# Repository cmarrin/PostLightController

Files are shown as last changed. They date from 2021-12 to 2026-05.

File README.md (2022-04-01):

# PostLightController

## Introduction
This is a controller for post lights along my fence. Each post has a NeoPixels 8 pixel ring and an Arduino Nano to drive it.
It receives serial data from a Raspberry Pi with 0-5v levels and no line conditioning other than 0.01uf capacitors on the input
and output serial lines. Data comes in on pin 11 and is sent out on pin 10. Post Light Controllers are connected in serial. The
previous controller sends data to the next. Each serial packet contains an address. An address of 0 sends the packet to all
controller, so every byte is simply passed on. If the address is 1, this packet is for the receiving controller. It consumes it
and doesn't send it on. If it is greater than 1 the address is decremented and the packet is sent to the next controller. So for
instance an address of 5 is consumed by the 5th controller in the chain.

SoftSerial is used to receive and send packets. Each packet consists of a variable number of bytes, starting with a lead-in ('('),
address, command and size. This is followed by <size> bytes of payload then by a checksum byte and a lead-out (')'). The command
tells the controller what sequence to run. For instance it can set a constant color ('c') of flicker the lights to looks like a
burning candle ('f'). The payload is specific to the command. But most commands start with a color as a byte each of hue,
saturation and value (brightness). 
	
## Interpreter
	
In order to avoid having to reprogram each post light controller whenever a command is added or changed, the system has an interpreter
for a custom language, Clover. See https://github.com/cmarrin/Clover. Clover uses the concepts of commands for calling functions to perform the various lighting effects. Because of the serial interface, commands for the post lights are a single character. You write a function for init and loop (in Arduino terms), indicate how many params are to be passed and associate it with a single character command string. The params passed to the serial interface must match the number of params specified in the command. The Interpreter init() function is called, passing the command and params. Those params are also available to the loop() function. The loop() function returns an int which is the number of milliseconds to delay before calling loop again. This allows accurate timing for the lighting effects.
	
Clover has a mechanism for adding modules, custom native functions for specific functionality. The post lights use a circular NeoPixel array with 8 addressable RGB LEDs (https://www.ebay.com/itm/392044823820). So the PostLightController adds a NativeColor module. This adds the concept of 4 color "registers" which can be manipulated by the functions in the module. There are functions to load a color (3 byte HSV) from the Params into one of the registers, loading and storing one color component (HSV) in one of the registers, and setting one light or all lights from a color register.

## Uploading
	
Commands are uploaded to the Aduino from the serial port in 64 byte binary chunks. The chunks are actually 66 bytes: 64 data bytes preceeded by a 2 byte offset of where to put the bytes in EEPROM. The Clover source is compiled on Mac into a series of 64 byte chunks saved to disk. A Node Red project (https://github.com/cmarrin/PondController-node-red-mac and https://github.com/cmarrin/PondController-node-red-mac) is used to upload. The Mac version is for testing but the system is intended to be run on a Raspberry Pi connected through its hardware serial port. You can connect to a PostLightController board from a USB to Serial board connected to the Mac and use the Node Red project to upload using the Send Executable button. See below for how to set up Node Red on Mac and RPi. The Mac compiler is a command line tool. You give it the Clover source file with the '-s' option to output a sequence of files with the same name as the input file minus the '.clvr' suffix, with a 2 digit sequence number and '.arlx'. These file are each 66 bytes long except for the last one, which is as long as needed.
	
## Installing Node-Red on Mac

To install the Node-Red PostLightController project on Mac, follow these steps:

1. Install Node.js (https://phoenixnap.com/kb/install-npm-mac).
2. Use the npm package manager to install Node-Red (https://nodered.org/docs/getting-started/local).
3. Clone the Mac Node-Red project (https://github.com/cmarrin/PondController-node-red-mac) into ~/.node-red/projects/PondController-node-red-mac/
4. In a Terminal shell run 'node-red'
	
The Node-Red Serial Out node is set to /dev/tty.usbserial-AD02CUJ5 for use with my USB to Serial board, which is similar to this one: https://www.ebay.com/itm/223507758747. Yours may be different. You can 'ls /dev/tty.usbserial-*' to see the name on your machine. If you have more than one board connected disconnect the others so you can positively identify the board you're using. Note that if you're connected directly connected to your Arduino to program it, that serial port will show up. Unplug it temporarily so you can find the one for your serial board.
	
Connect to the PostLightController board from your USB to Serial board by connecting Vcc and Gnd to the corresponding pins on the PostLightController input connector (pins 1 and 2), and the serial board's TXD output to the PostLightController input (pin 3). Then copy all the .arlx files to ~/ and hit the Send Executable button. Of course make sure you build and install PostLightController.ino to the Arduino first.

## TODO
- [x] Get rid of color table
- [x] Create a Color class which takes rgb or hsv values and can give back color as uint32_t (0x00RRGGBB) or hsv (3 floats 0-1)
- [x] Make all effects use Color class
- [x] Make payload a binary array, colors are 3 bytes: hue, sat and val, all 0-255
- [x] Make node-red generate colors in new format
- [x] Get rid of new to create Effects. Create one of each and point to it as needed
- [x] Write Arly Compiler
- [x] Write Arly test file, implementing ConstantColor and Flicker commands
- [x] Write Decompiler to see what code is getting generated
- [x] Write Interpreter for code
- [x] Write Simulator on Mac, specializing Interpreter and printing out pixel values, etc.
- [x] Add Interpreter to Arduino as a subclass of Effect
- [x] Add command(s) to upload Arly executable to Arduino
- [x] Add interpreted commands to node-red
- [x] Once everything is working remove ConstantColor and Flicker classes
- [x] Change packet to be variable length: start ('('), device addr ('0' = all devices), cmd, payload len (0-63), checksum, end (')')
- [x] Make node-red use variable length format

## Board Fab
To send PostLightController board to seeedstudio (https://www.seeedstudio.com/fusion_pcb.html):

	1) open PostLightController.kicad_pcb

	2) go to File->Plot...

	3) Make sure Use Extended X2 Format is not checked

	4) Make sure Output folder is 'gbr/'

	5) Press Plot to generate all the files

	6) Press Generate Drill Files...

	7) Press Generate Drill Files on the sheet that comes up

	8) Go to console in the PostLightController directory and run 'zip PostLightController-gbr.zip gbr/*'

	9) Upload the resulting PostLightController-gbr.zip to SeeedStudio

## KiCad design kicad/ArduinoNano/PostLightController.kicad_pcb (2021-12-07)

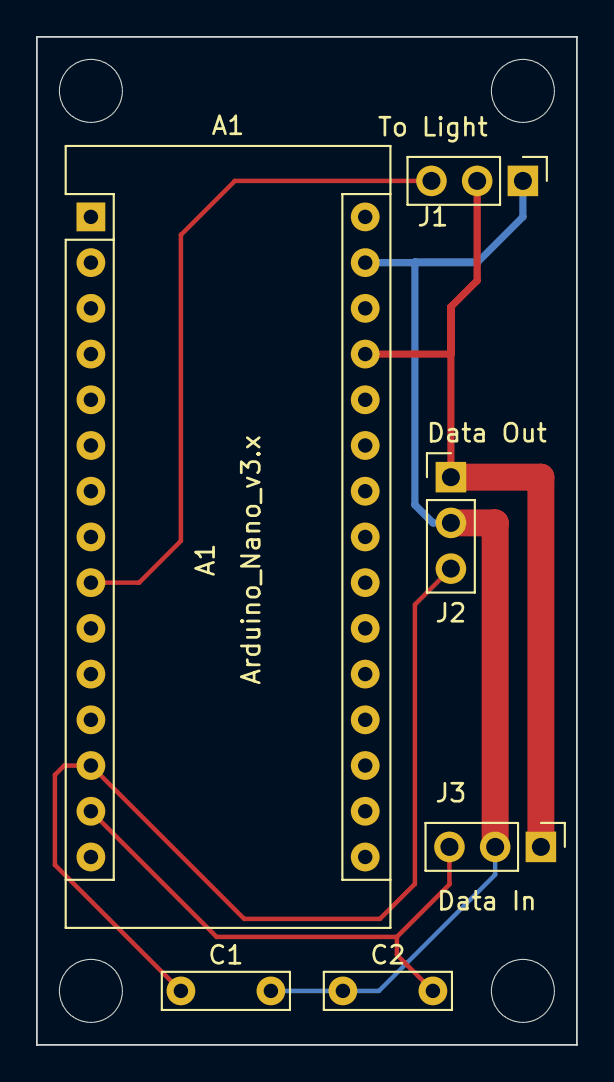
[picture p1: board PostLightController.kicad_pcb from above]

Board: 2 copper layers, 30.0 x 56.0 mm, 6 parts (0 on the bottom side), 5 nets.

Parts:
A1: Arduino_Nano_v3.x; Arduino_Nano
C1, C2: C; C_Rect_L7.0mm_W2.0mm_P5.00mm
J1: To Light; Pin_Header_Straight_1x03_Pitch2.54mm
J2: Data Out; Pin_Header_Straight_1x03_Pitch2.54mm
J3: Data In; Pin_Header_Straight_1x03_Pitch2.54mm

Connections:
unnamed: A1.9, J1.3
unnamed: A1.13, C1.1, J2.3
unnamed: A1.14, C2.1, J3.3
unnamed: A1.27, J1.2, J2.1, J3.1
unnamed: A1.29, C1.2, C2.2, J1.1, J2.2, J3.2

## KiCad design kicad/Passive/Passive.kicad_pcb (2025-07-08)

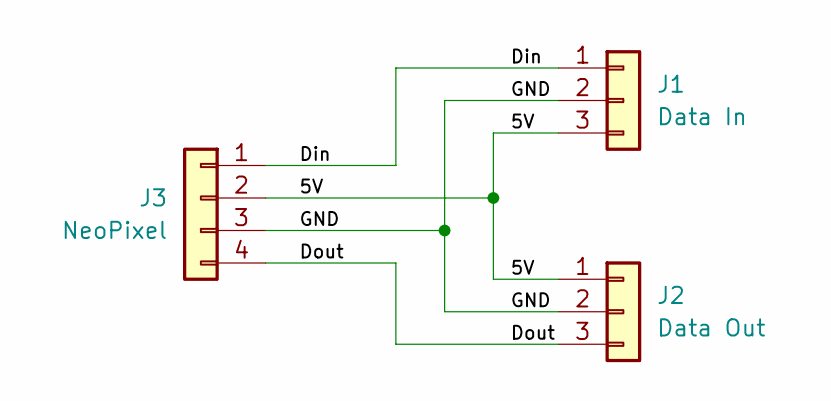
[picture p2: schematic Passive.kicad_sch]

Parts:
J1: Data In; PinHeader_1x03_P2.54mm_Horizontal
J2: Data Out; PinHeader_1x03_P2.54mm_Horizontal
J3: NeoPixel; PinHeader_1x04_P2.54mm_Horizontal

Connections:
/5V: J1.3, J2.1, J3.2
/Din: J1.1, J3.1
/Dout: J2.3, J3.4
/GND: J1.2, J2.2, J3.3

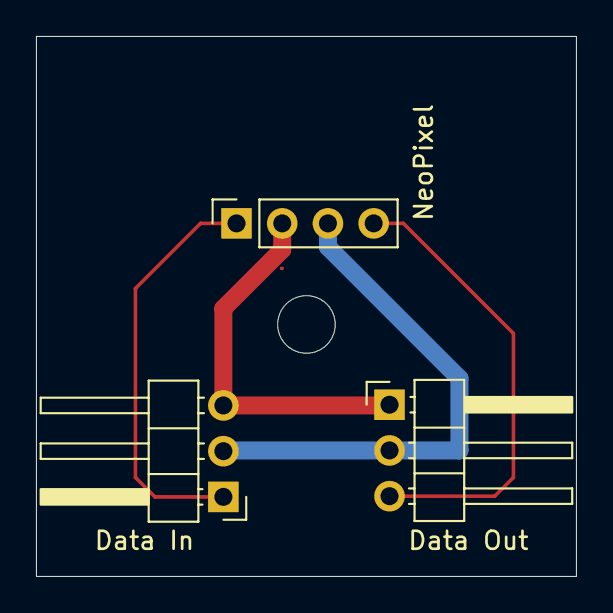
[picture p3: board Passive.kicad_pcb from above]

Board: 2 copper layers, 30.0 x 30.0 mm, 3 parts (0 on the bottom side), 4 nets.

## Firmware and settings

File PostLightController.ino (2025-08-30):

/*-------------------------------------------------------------------------
    This source file is a part of Clover
    For the latest info, see https://github.com/cmarrin/Clover
    Copyright (c) 2021-2022, Chris Marrin
    All rights reserved.
    Use of this source code is governed by the MIT license that can be
    found in the LICENSE file.
-------------------------------------------------------------------------*/

#if !defined(ESP8266) && !defined(ESP32)

/*

Pond Light Controller

Each controller is a 5V Arduino Nano with serial data coming in on pin D11 and out on pin
D10. Data is output to an 8 pixel WS2812 ring on D6. Serial data, +5V and Gnd comes into 
each post and goes out to the next post.

Serial Protocol

Standard RS232 protocol is used with 1 start bit, 8 data bits and 1 stop bit. Bit rate is
set by the protocol from 1200 bps to 57600 bps. Bit rate is currently fixed at 300 baud.

Each command has a series of bytes with the format:

	Lead-in		'('
	Address		Which controller this command is for (0 is all devices)
	Command		Single char command 
	Size		Payload size in bytes
	Payload		Bytes of payload (in binary)
	Checksum	One byte checksum
	Lead-out	')'

All characters but the payload and payload size are between 0x30 and 0x6f. Max payload size is
256 bytes. Checksum is computed by adding all characters of the buffer, including leading and 
ending characters, truncating the result to 6 bits and adding 0x30 to the result. For purposes 
of computing checksum, a '0' is placed in the checksum location.

To allow for interpreted commands each "normal" command (those which cause the lights to do a 
pattern) are limited to 16 bytes. This is enough for 4 colors (12 bytes) plus 4 byte params. The only
command which can exceed this is the 'X' command.

Command List:

   Command 	Name         	Params						Description
   -------  ----            ------    					-----------
	'C'     Constant Color 	color, n, d					Set lights to passed color
                                                        Flash n times, for d duration (in 100ms units)
                                                        If n == 0, just turn lights on

	'X'		EEPROM[0]		addr, <data>				Write EEPROM starting at addr. Data can be
														up to 64 bytes, due to buffering limitations.

			Rainbow			color, speed, range, mode	Change color through the rainbow by changing hue 
														from the passed color at the passed speed. Range
														is how far from the passed color to go, 0 (very little)
														to 7 (full range). If mode is 0 colors bounce 
														back and forth between start color through range. If
														it is 1 colors cycle the full color spectrum and
														range is ignored.

A Color param is 3 consecutive bytes (hue, saturation, value). Saturation and value are levels between 0 and 255.
Hue is an angle on the color wheel. A 0-360 degree value is obtained with hue / 256 * 360.

*/

#include <SoftwareSerial.h>

#include "Flash.h"
#include "InterpretedEffect.h"

constexpr int LEDPin = 6;
constexpr int NumPixels = 8;
constexpr int MaxPayloadSize = 1017; // 1024 - 7 (the size of the header + footer)
constexpr int CommandSizeBefore = 5;
constexpr int CommandSizeAfter = 2;
constexpr char StartChar = '(';
constexpr char EndChar = ')';
constexpr unsigned long SerialTimeOut = 2000; // ms
constexpr int32_t MaxDelay = 1000; // ms

class PostLightController
{
public:
	PostLightController()
		: _pixels(NumPixels, LEDPin)
		, _serial(11, 10)
		, _interpretedEffect(&_pixels)
	{
        _buf = _interpretedEffect.stackBase();
    }

	~PostLightController() { }
	
	void setup()
	{
	    Serial.begin(115200);
        while (!Serial) ; // wait for Arduino Serial Monitor to open
	    _serial.begin(2400);
		
		delay(500);

        randomSeed(millis());

        Serial.print(F("Post Light Controller v0.4\n"));
      
		showStatus(StatusColor::Green, 3, 2);
		
		_timeSinceLastChar = millis();
	}

	void loop()
	{
		int32_t delayInMs = 0;
        if (_effect == Effect::Flash) {
            delayInMs = _flash.loop(&_pixels);
        } else if (_effect == Effect::Interp) {
            delayInMs = _interpretedEffect.loop();
        }
        
        if (delayInMs > MaxDelay) {
            delayInMs = MaxDelay;
        }
		
		if (delayInMs < 0) {
			// An effect has finished. End it and clear the display
			showColor(0, 0, 0, 0, 0);
            _effect = Effect::None;
			delayInMs = 0;
		}
		
		uint32_t newTime = millis();

		// If we're capturing and it's been a while, error
		if (_state != State::NotCapturing) {
			if (newTime - _timeSinceLastChar > SerialTimeOut) {
				_state = State::NotCapturing;
				Serial.print(F("***** char timeout, rst\n"));
				showStatus(StatusColor::Red, 3, 2);
				_state = State::NotCapturing;
			}
		}

	    if (_serial.available()) {
			_timeSinceLastChar = newTime;
			
			char c = char(_serial.read());
			
			// Run the state machine
			
			switch(_state) {
				case State::NotCapturing:
					if (c == StartChar) {
                        _bufIndex = 0;
                        _buf[_bufIndex++] = c;
						_state = State::DeviceAddr;
						_expectedChecksum = c;
                        _cmdPassThrough = false;
                        _cmdExecute = false;
					}
					break;
				case State::DeviceAddr:
                    if (c == '0') {
                        // If addr is '0' then this command is for all devices.
                        // Execute it and pass it through.
                        _cmdPassThrough = true;
                        _cmdExecute = true;
                    } else if (c == '1') {
                        // If addr is '1' then this command is for this
                        // device only. Execute but don't pass through.
                        _cmdPassThrough = false;
                        _cmdExecute = true;
                    } else {
                        // If addr is greater than '1' then this command
                        // is for another device. decrement the address
                        // and pass it along.
                        _cmdPassThrough = true;
                        _cmdExecute = false;
                        c -= 1;
                    }
                    
                    _buf[_bufIndex++] = c;
                    _state = State::Cmd;
					_expectedChecksum += c;
					break;
				case State::Cmd:
                    _buf[_bufIndex++] = c;
					_cmd = c;
					_state = State::SizeHi;
					_expectedChecksum += c;
					break;
				case State::SizeHi:
                    _buf[_bufIndex++] = c;
					_state = State::SizeLo;
					_payloadSize = uint16_t(c) << 8;
					_expectedChecksum += c;
					break;
				case State::SizeLo:
                    _buf[_bufIndex++] = c;
					_payloadSize |= uint16_t(uint8_t(c));
                    _payloadReceived = 0;
                    Serial.print(F("Buffer size="));
                    Serial.println(_payloadSize);
					
                    if (_payloadSize > MaxPayloadSize) {
						Serial.print(F("Buf too big. Size="));
						Serial.println(_payloadSize);
						showStatus(StatusColor::Red, 6, 1);
						_state = State::NotCapturing;
					} else {
						_state = State::Data;
						_expectedChecksum += c;
					}

                    if (_cmd == 'X') {
                        showStatus(StatusColor::Blue, 0, 0);
                    }
					break;
				case State::Data:
					_buf[_bufIndex++] = c;
                    _payloadReceived++;
					_expectedChecksum += c;
					
					if (_payloadReceived >= _payloadSize) {
						_state = State::Checksum;
					}
					break;
				case State::Checksum: {     
                    // If we're passing through and not executing, we've decremented
                    //  the address so we have to decrement the checksum as well
					_actualChecksum = (_cmdPassThrough && !_cmdExecute) ? (c - 1) : c;
					_buf[_bufIndex++] = _actualChecksum;
					_state = State::LeadOut;
					_expectedChecksum += '0';
					break;
				}
				case State::LeadOut:
					if (c != EndChar) {
						Serial.println(F("Exp lead-out"));
						showStatus(StatusColor::Red, 6, 1);
						_state = State::NotCapturing;
					} else {
                        _buf[_bufIndex++] = c;
                        
						// Make sure checksum is right
						_expectedChecksum += c;
						_expectedChecksum = (_expectedChecksum & 0x3f) + 0x30;
						
						if (_expectedChecksum != _actualChecksum) {
							Serial.print(F("CRC ERROR: exp="));
							Serial.print(_expectedChecksum);
							Serial.print(F(", actual="));
							Serial.print(_actualChecksum);
							Serial.print(F(", cmd: "));
							Serial.println(_cmd);
							showStatus(StatusColor::Red, 5, 5);
							_state = State::NotCapturing;
						} else {
							// Have a good buffer
							_state = State::NotCapturing;

                            if (_cmd == 'X') {
                                showStatus(StatusColor::Yellow, 0, 0);
                            }

                            // Pass through buffer if needed
                            if (_cmdPassThrough) {
                                for (uint16_t i = 0; i < _payloadSize + CommandSizeBefore + CommandSizeAfter; i++) {
                                    _serial.write(_buf[i]);
                                }
                            }
       
                            if (_cmd == 'X') {
                                showStatus(StatusColor::Green, 0, 0);
                            }

                            if (!_cmdExecute) {
                                break;
                            }
                            
                            // Handle the command
                            _effect = Effect::None;
							
							switch(_cmd) {
								case 'C':
								showColor(_buf[CommandSizeBefore], 
                                          _buf[CommandSizeBefore + 1], 
                                          _buf[CommandSizeBefore + 2], 
                                          _buf[CommandSizeBefore + 3], 
                                          _buf[CommandSizeBefore + 4]);
								break;
								
								case 'X': {
									// Cancel effect
                                    _effect = Effect::None;
									
									if (_payloadSize > 1024) {
										Serial.print(F("inv EEPROM size="));
										Serial.println(_payloadSize);
										showStatus(StatusColor::Red, 5, 5);
										_state = State::NotCapturing;
									} else {
										Serial.print(F("exec => EEPROM: size="));
										Serial.println(_payloadSize);

										for (uint16_t i = 0; i < _payloadSize; ++i) {
											EEPROM[i] = _buf[i + CommandSizeBefore]; // Skip cmd chars and start addr
										}
									}
                                    Serial.println(F("Finished upload"));
                                    showStatus(StatusColor::Blue, 5, 1);
									break;
								}
								default:
								// See if it's interpreted, payload is after cmd bytes, offset it
								if (!_interpretedEffect.init(_cmd, _buf + CommandSizeBefore, _payloadSize)) {
									String errorMsg;
									switch(_interpretedEffect.error()) {
                                        case clvr::Memory::Error::None:
                                        errorMsg = F("---");
                                        break;
                                        case clvr::Memory::Error::InvalidSignature:
                                        errorMsg = F("bad signature");
                                        break;
                                        case clvr::Memory::Error::InvalidVersion:
                                        errorMsg = F("bad  version");
                                        break;
                                        case clvr::Memory::Error::WrongAddressSize:
                                        errorMsg = F("wrong addr size");
                                        break;
                                        case clvr::Memory::Error::NoEntryPoint:
                                        errorMsg = F("no entry point");
                                        break;
                                        case clvr::Memory::Error::NotInstantiated:
                                        errorMsg = F("not instantiated");
                                        break;
                                        case clvr::Memory::Error::UnexpectedOpInIf:
                                        errorMsg = F("bad op in if");
                                        break;
                                        case clvr::Memory::Error::InvalidOp:
                                        errorMsg = F("inv op");
                                        break;
                                        case clvr::Memory::Error::OnlyMemAddressesAllowed:
                                        errorMsg = F("mem addrs only");
                                        break;
                                        case clvr::Memory::Error::AddressOutOfRange:
                                        errorMsg = F("addr out of rng");
                                        break;
                                        case clvr::Memory::Error::ExpectedSetFrame:
                                        errorMsg = F("SetFrame needed");
                                        break;
                                        case clvr::Memory::Error::InvalidModuleOp:
                                        errorMsg = F("inv mod op");
                                        break;
                                        case clvr::Memory::Error::NotEnoughArgs:
                                        errorMsg = F("not enough args");
                                        break;
                                        case clvr::Memory::Error::WrongNumberOfArgs:
                                        errorMsg = F("wrong arg cnt");
                                        break;
                                        case clvr::Memory::Error::StackOverrun:
                                        errorMsg = F("can't call, stack full");
                                        break;
                                        case clvr::Memory::Error::StackUnderrun:
                                        errorMsg = F("stack underrun");
                                        break;
                                        case clvr::Memory::Error::StackOutOfRange:
                                        errorMsg = F("stack out of range");
                                        break;
                                        case clvr::Memory::Error::ImmedNotAllowedHere:
                                        errorMsg = F("immed not allowed here");
                                        break;
                                        case clvr::Memory::Error::InternalError:
                                        errorMsg = F("internal err");
                                        break;
									}

									Serial.print(F("Interp fx err: "));
									Serial.println(errorMsg);
									showStatus(StatusColor::Red, 5, 1);
									_state = State::NotCapturing;
								} else {
                                    _effect = Effect::Interp;
								}
								break;
							}
						}
					}

					break;
			}
	  	}

		// Eventually we can't delay in loop because we have to feed the soft serial port
		// But for now...
		delay(delayInMs);
	}

private:
	static uint8_t checksum(const char* buf, int length) 
	{
	    uint8_t sum = 0;

	    for (int i = 0; i < length; i++) {
			sum += buf[i];
	    }
	    return sum & 0x3f;
	}

	enum class StatusColor { Red, Green, Yellow, Blue };

	void showColor(uint8_t h, uint8_t s, uint8_t v, uint8_t n, uint8_t d)
	{
        _effect = Effect::Flash;
        _flash.init(&_pixels, h, s, v, n, d);
	}
	
	void showStatus(StatusColor color, uint8_t numberOfBlinks = 0, uint8_t interval = 0)
	{
		// Flash half bright red or green at passed interval and passed number of times
        _effect = Effect::Flash;
        uint8_t h = 128;
        
        switch (color) {
            case StatusColor::Red: h = 0; break;
            case StatusColor::Green: h = 85; break;
            case StatusColor::Yellow: h = 30; break;
            case StatusColor::Blue: h = 140; break;
        }
        _flash.init(&_pixels, h, 0xff, 0x80, numberOfBlinks, interval);
	}
	
	NeoPixel _pixels;
	SoftwareSerial _serial;
	
    enum class Effect { None, Flash, Interp };
    Effect _effect = Effect::None;
	Flash _flash;
	InterpretedEffect _interpretedEffect;
	
    // We share the incoming buffer with the interpreter stack
	uint8_t* _buf = nullptr;
	uint16_t _bufIndex = 0;
    
    uint16_t _payloadReceived = 0;
	uint16_t _payloadSize = 0;
    
	unsigned long _timeSinceLastChar = 0;
	
	uint8_t _expectedChecksum = 0;
	uint8_t _actualChecksum = 0;
	
	uint8_t _cmd = '0';
 
    bool _cmdPassThrough = false;
    bool _cmdExecute = true;
	
	// State machine
	enum class State { NotCapturing, DeviceAddr, Cmd, SizeHi, SizeLo, Data, Checksum, LeadOut };
	State _state = State::NotCapturing;
};

PostLightController controller;

void setup()
{
	controller.setup();
}

void loop()
{
	controller.loop();
}

#endif

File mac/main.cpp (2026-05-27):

/*-------------------------------------------------------------------------
    This source file is a part of Clover
    For the latest info, see https://github.com/cmarrin/Clover
    Copyright (c) 2021-2022, Chris Marrin
    All rights reserved.
    Use of this source code is governed by the MIT license that can be
    found in the LICENSE file.
-------------------------------------------------------------------------*/

#include "PostLightController.h"

#include "MacWiFiPortal.h"
#include "tigr.h"

#include <numbers>
#include <cmath>
#include <condition_variable>

mil::MacWiFiPortal portal;

static const char* TAG = "PostLightController";

static constexpr double PI = std::numbers::pi;
static constexpr int LEDsPerRing = 8;
static constexpr double AnglePerLED = 2 * PI / LEDsPerRing;
static constexpr int LEDRadius = 10;
static constexpr int RingCount = 7;
static constexpr int RingSize = 80;
static constexpr int Spacing = 50;
static constexpr int WindowWidth = RingSize * RingCount + Spacing * (RingCount + 1);
static constexpr int WindowHeight = RingSize + Spacing * 2;

static void polarToCartesian(double angle, int radius, int& x, int& y)
{
    x = std::cos(angle) * radius;
    y = std::sin(angle) * radius;
}

static void colorToRGB(uint32_t color, uint8_t& r, uint8_t& g, uint8_t& b)
{
    r = (color >> 16) & 0xff;
    g = (color >> 8) & 0xff;
    b = color & 0xff;
}

static void makeRing(Tigr* bitmap, const uint32_t* buffer, int centerX, int centerY)
{
    double angle = 0;
    
    for (int i = 0; i < LEDsPerRing; ++i) {
        int x;
        int y;
        polarToCartesian(angle, RingSize / 2, x, y);
        uint32_t color = buffer[i];
        uint8_t r, g, b;
        colorToRGB(color, r, g, b);
        tigrFillCircle(bitmap, x + centerX, y + centerY, LEDRadius, tigrRGB(r, g, b));
        angle += AnglePerLED;
    }
}

int main(int argc, char * const argv[])
{
    static std::mutex _mutex;
    static std::condition_variable _statusCond;
    
    std::thread::id myThreadId = std::this_thread::get_id();
    
    bool needRender = false;
    
    while (true) {
        mil::System::logI(TAG, "Opening tigr window");

        Tigr* screen = tigrWindow(WindowWidth, WindowHeight, "PostLightController", TIGR_AUTO);
        Tigr* bitmap = tigrBitmap(WindowWidth, WindowHeight);
        
        mil::System::setRenderCB([bitmap, &needRender, myThreadId](const mil::Graphics* gfx)
        {
            std::unique_lock<std::mutex> lk(_mutex);
            const uint32_t* b = reinterpret_cast<const uint32_t*>(gfx->getBuffer());
            tigrClear(bitmap, tigrRGBA(0x0, 0x00, 0x00, 0xff));

            int16_t width = gfx->width();

            int x = RingSize / 2 + Spacing;
            for (int i = 0; i < RingCount; ++i) {
                if (width >= LEDsPerRing) {
                    makeRing(bitmap, b + LEDsPerRing * i, x, RingSize / 2 + Spacing);
                }
                x += RingSize + Spacing;
                width -= LEDsPerRing;
                if (width <= 0) {
                    break;
                }
            }
            needRender = true;
        });

        PostLightController controller(&portal);
        
        controller.setup();
        
        while (!tigrClosed(screen) && !tigrKeyDown(screen, TK_ESCAPE)) {
            if (mil::System::isRestarting()) {
                break;
            }
            
            controller.loop();
            {
                std::unique_lock<std::mutex> lk(_mutex);
                if (needRender) {
                    needRender = false;
                    tigrBlit(screen, bitmap, 0, 0, 0, 0, WindowWidth, WindowHeight);
               }
            }
            tigrUpdate(screen);
            mil::System::delay(10);
        }

        tigrFree(bitmap);
        tigrFree(screen);
    }
    
    return 1;
}

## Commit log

2021-11-05 Added Serial input for commands
    SoftwareSerial is used on pin 10 (rx) and 11 (tx). Packets are 8 bytes and contain a checksum. Checksum is computed and compared. If they match the command is processed. Right now the command is just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
2021-12-07 Added Kicad files
    [PostLightController.kicad_pcb, PostLightController.sch]
2022-01-07 Added a Flash effect, which flashes a color on and off at a passed rate for a passed number of cycles.
    This is used to show errors. I changed several sequences for reliability and added a Flash when one of a number of errors occurs. I also Flash green 3 times on startup to show the light is alive. When the flashing finishes it return -1 which destroys the Flash object and replaces it with a ConstantColor of 0. I also added a 500ms delay to startup which seems to make the startup flash more reliable. Finally, taking too long for a byte to come in used to just ignore the command. Now it generates and error flash.
    [PostLightController.ino]
2022-01-09 Changed payload to be binary, with 3 byte colors
    Color is now hue, sat, val as 3 bytes 0-255. packet is still fixed at 10 bytes. Node-red on Mac sends this format now. Still need to make changes to rpi
    [PostLightController.ino]
2022-01-11 Finished Arly compiler
    Right now it just compiles and follows the right syntax. Not tested. I'm pretty sure I need to add some retireTokens() in various places. And it doesn't generate any code or print any errors
2022-01-12 Checkpoint
    Compiler successfully compiles test case and stores the constant data and symbol table. But nothing generated yet.
2022-01-12 Checkpoint
    Now handle opcodes with the correct sequence of registers, ids and indexes. Are storing opcodes in _rom8
    [main.cpp]
2022-01-13 Got code generating. It looks correct in the binary file
    [main.cpp]
2022-01-15 Added Interpreter class.
    This will be the base class that runs on both Arduino and Mac. It will have virtual methods to talk to the real or simulated hardware. For now it's just a shell
2022-01-15 Separated Color to its own file
    This compiles on both Arduino and Mac. I brought in the hsvToRGB function from Adafruit to allow Mac to use it
2022-01-15 Moved Interpreter to parent directory so it can be used by both Mac and Arduino
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2022-01-16 Starting to get Arly Interpreter running
    Making all the calls to test the 'c' and 'f' commands and checking errors. Not yet loading the executable so nothing works.
    [Interpreter.h, main.cpp]
2022-01-16 Checkpoint
    Filling ROM in simulator and calling the correct addresses for init and loop. But interpreter itself still does nothing
    [main.cpp]
2022-01-17 Implemented majority of interpreter.
    Still not working
    [Interpreter.h, main.cpp]
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2022-01-17 Fixed a few errors in Mac
    [main.cpp]
2022-01-17 Added dummy subclass implementation of Interpreter for Arduino
    This is just to see how big the Arduino executable is. It comes in at 12.3K of code and 1380 bytes of variable space.
2022-01-18 Fixed mem vs const access
    Ids can be 0-0x7f for constants and 0x8000xff for mem addresses. Added functions that take Ids for all operations so that can be determined. All the store ops only work for RAM, so return error if not
    [Interpreter.h, main.cpp]
2022-01-18 Added print of pc addr in decompiled output and pc addr where error occured in interpreter
    [Interpreter.h, main.cpp]
2022-01-18 Added more iterations for 'f' command and extra prints to try to track down why it's not animating
2022-01-18 Added Logging opcodes
    There is now Log, LogFloat and LogColor. Pass a register param and they print the contents of that register along with the address with the Log statement. For debugging
2022-01-18 Fixed bug in fetching int32 from ROM
    [Interpreter.h]
2022-01-18 Was computing the wrong Sz value for if-else case
    Sz for the if-else case was skipping the else as well as the if
2022-01-18 Was using the wrong index value for accessing the leds array
    I was using the foreach index directly. But each entry has 3 float, so I multplied it by 3 and store that in r3 to use everywhere
2022-01-18 Fixed bug where I was trashing r3.
    I need an extra reg, so I was using r3 which has the index into the leds array. So I store it off while using r3
2022-01-19 Fixed bugs to get variable length buffers working
    [PostLightController.ino]
2022-01-20 Got interpreted effect working on Controller
    - Added InterpretedEffect Effect which calls the interpreter.
    - Pass cmd to init so interpreter can see it
    - Have init return false if cmd does not exist
    - Implemented EEPROM reading in Device
    - Added show() to setLight
    The 'c' command now works
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2022-01-20 Added better error printing for interpreted commands
    [PostLightController.ino]
2022-01-20 Fix bug where setting color to 0 would not stop animation
    [PostLightController.ino]
2022-01-20 Got rid of Black StatusColor
    No longer needed now that we have showColor()
    [PostLightController.ino]
2022-01-21 Copy params to Interpreter to avoid them getting overwritten
    [Interpreter.h]
2022-01-21 Cancel running animation when doing 'X' command so it doesn't interfere with upload
    [PostLightController.ino]
2022-01-26 Replaced Random with RandomFloat and RandomInt
    They now take the same type of parameters as the return value. RandomFloat uses the random() function which works with int32_t. To get a floating point value I multiply the min and max by 1000, do random and then convert to float and divide by 1000. This reduces the range from 2 billion to 2 million, which should be fine.
    [Interpreter.h]
2022-01-26 Changed Arly to have LED values from 0 to 1 rather than 0-255
    Before, the brightness was calculated in floats, but they were in 0-255 units, so they had to be converted to 0-1 before sending to the light. Now it's always 0-1 so no conversion is needed
2022-01-26 Got rid of LoadByteMax, LoadIntOne and LoadFloatOne
    Added LoadIntConst to replace them. This will allow loading other constants from 0-255. To load a float 1 you'll need to LoadIntConst r0 1 and ToFloat r0.
    [Interpreter.h]
2022-01-27 Fixed error output
    Before it was only showing errors for loop, not init
    [main.cpp]
2022-01-27 Added support for Call/Return
    New opcodes for Call and Return. Call has a target param which is 10 bit address relative to the start of code. A _codeOffset variable was added to get the absolute address of the Call. Upper 8 bits of the address are in the byte following the opcode, the lower 2 bits are in the lowest 2 bits of the opcode. So the opcode in in the 0x80 and above range. When Call is executed a 16 entry call stack saves the return pc address and then we jump to target + _codeOffset. When Return is executed, the previously pushed return address is popped and replaces _pc. All param passing and return values are by agreement between the caller and callee.
    [Interpreter.h]
2022-01-27 Added missing Error cases to Arduino
    [PostLightController.ino]
2022-01-28 Added error checking to random function
    [Interpreter.h]
2022-01-28 Added error checking to RAM int storage call
    [Interpreter.h]
2022-01-29 Replaced LoadVal and StoreVal with LoadColorComp and StoreColorComp
    When before you said LoadVal r0 c1 you'd now say LoadColorComp r0 c1 2. Takes the same amount of space and now you can load and store Hue and Saturation.
    [Interpreter.h, main.cpp]
2022-01-29 Added missing enum to Arduino
    [PostLightController.ino]
2022-01-30 Got rid of unused underrun error
    [Interpreter.h, PostLightController.ino, main.cpp]
2022-01-30 Converted Arly source to Clover
    This doesn't match the current syntax in CloverCompileEngine
2022-02-01 Added LoadTemp and StoreTemp
    These are not yet tested. I'm adding them so I have a place to store temps as processing expressions at runtime. Right now there are slots for 4 temps with the address in the lower 2 bits of the op. 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
2022-02-02 Getting closer with Clover compiler syntax
    I commented out the program in PostLightController.clvr and replaced it with a simple program. It compiles without error, but doesn't generate any code yet, so it fails to run.
    [main.cpp]
2022-02-03 Redesigned variable handling
    I've realized I need both global and local variables. Globals can be shared (for instance between init and loop). Locals allow you to save space because they are only active inside a function.
    Now if an id is < 0x80 it is a constant (const or table), 0x80 to 0xbf is a global var (in the _global array) and from 0xc0 to 0xff is a local, relative to the _bp for the current function. Locals are not being generated yet, so they are untested. But the code to handle them is there. Functions now use a _bp to identify the start of local storage. It is loaded and restored on function call and return, but it is untested. The .arly test mostly works. But for some reason two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
    [Interpreter.h, main.cpp]
2022-02-05 WIP - Started handling native functions
    Lots of restructuring. Now Symbol and Function are classes. All dealing with addresses of the different Storage classes are handed inside Symbol. Function now contains a list of formal params and can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
2022-02-07 Got simple Clover test case working
    Still some work to do with error checking. But this simple test works
    [Interpreter.h, main.cpp]
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2022-02-07 Added missing enums for Arduino
    [PostLightController.ino]
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2022-02-07 Replaced built-in SetLight and Animate opcodes with NativeFunction versions
    Added these to Arly test case. Everything works on Arduino with the Arly code
    [Interpreter.h]
2022-02-10 WIP - Changing engine to be a stack machine
    Builds and can compile new Arly format source code. But doesn't work yet. Outputs all zeroes. And the Clover code generator is certainly completely broken
    [Interpreter.h, main.cpp]
2022-02-10 Moved all interpreter stack access to Stack class
    This gives better control over stack variables and allows more error checking
    [Interpreter.h, main.cpp]
2022-02-10 Fixed bugs in interpreter and Arly code.
    the 'c' and 'p' commands now work
    [Interpreter.h, main.cpp]
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2022-02-10 Fixed some issues with Arduino build
    [Interpreter.h, PostLightController.ino]
2022-02-10 Changed _stackk to _stack
    This was just done while I was switching over to the Stack class.
2022-02-10 Fixed Flicker effect.
    All effects now work on Arduino with stack based machine
    [main.cpp]
2022-02-13 WIP - grammar was wrong and now its starting to work
    - I had the grammar wrong for chained operations. You could not have 'a[i].b' because you couldn't chain postfix operations. That's all fixed now.
    - That chain operation and others now work.
    - Started getting binary operations to work. Still need to complete the work and add logic for the rest of the operators
    - Currently always generating ops for Int binary operations, which is wrong. Need to determine type of right and left sides and do error handling
    - Next I will separate out assignment operators from the other. I won't be supporting chained assignment.
2022-02-14 Added charno support
    Now Error output includes charno as well as lineno
    [main.cpp]
2022-02-14 Added error checking for going past EOF to decompiler
    [main.cpp]
2022-02-14 Implemented all binary ops.
    Now the complex chained calculation in the .clvr file is properly parsed and generated.
2022-02-15 Made all the mem pointers into int16_t for error checking
    [Interpreter.h]
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2022-02-15 Got rid of Min and Max opcodes and added native function replacements
    [Interpreter.h]
2022-02-15 Do checking for correct number of args in init()
    [Interpreter.h, main.cpp]
2022-02-16 Fixed Arduino file so it compiles
    [PostLightController.ino]
2022-02-17 Added reinit of Stack variables on alloc.
    This fixes a bug when an effect error exits
    [Interpreter.h]
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2022-02-21 Fixed a couple of bugs with annotations in Arly decompile
2022-02-22 Made for loops nestable.
    Got rid of ForEach and EndForEach. Replaced them with Loop (jump backwards) and Jump (jump forward). A for loop now has an if statement at the top which tests the variable against the end value. If >= it does a break, which jumps to the end of the loop. At the end of the for statement is an increment of the variable followed by a Loop instruction back to the beginning. No more member variables holding values for the loop, so loops can be nested. The engine supports the concept of 'break' and 'continue' but those statements are not implemented yet.
    [Interpreter.h, main.cpp]
2022-02-22 WIP - Moved files around into new structure so I can make them into a library
    I nuked all the color specific native functions so nothing works. But I'll put it all back together shortly. And Arduino won't work anymore
    [Interpreter.h, main.cpp]
2022-02-23 Got rid of Gamma from Color.
    Went back to using NeoPixel code. This will only be used in Arduino, so it's ok
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2022-02-23 Added a dummy Clover.h
    This just includes interpreter.h. This makes it so you can #include <Clover.h> in Arduino for clarity
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2022-02-23 Added Arduino files to XCode just so I can look at them
2022-02-24 Move all native functions into modules
    These are loaded at compile and runtime to add the needed functionality. Tested on Mac and Arduino. Everything is back to working
2022-02-26 Simplified runtime error messages to save space
    [PostLightController.ino, main.cpp]
2022-02-27 Fixed arduino to work with new command strings
2022-03-02 Fixed issue with not setting lang
    [main.cpp]
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2022-03-10 Added more error messages
    [main.cpp]
2024-01-01 Fixed bugs in keeping track of payload size
    Renamed some vars to make it more clear what we're keeping track of. Now all commands and executable upload all work
    [PostLightController.ino]
2024-01-24 Change baud rate to 1200
    Node-red has a bug where it can't send serial at any speed less than 1200
    [PostLightController.ino]
2024-01-24 Fix bug where checksum is wrong when passing through
    Sometimes address is changed when passing through, which changes checksum. Fix checksum to match
    [PostLightController.ino]
2024-01-24 More of passthrough checksum fix
    [PostLightController.ino]
2024-01-24 Fixes to status lights
    Make colors half-bright. Full bright is too bright. Also make yellow more yellow
    [PostLightController.ino]
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2025-06-04 Switched to new PostLightController logic
    This was developed as part of the Clover project and ported over here.
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2025-06-23 WIP - Get new code working on Mac
    This adds a PostLightController class which has all the common functionality for Mac and ESP. Got the code working on Mac somewhere (doesn't seem to loop). But PostLightControllerESP.ino is not finished
    [PostLightControllerESP.ino, main.cpp]
2025-06-25 Fixed a print
2025-06-26 Moved uploadExecutable to common PostLightController class
    Eventually both Mac and ESP will store the executable in the WebFIleSystem. For now is just stores it in a block of RAM
    [partitions.csv]
2025-06-26 Added custom partition file
    This also added a boards.local.txt file which is supposed to allow a custom partitions.csv file. But it doesn't work so for now these lines are added to ~/Library/Arduino15/packages/esp32/hardware/esp32/3.2.0/boards.txt
    [partitions.csv]
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2025-06-30 Changed custom partitions file
    Looks like the SPIFFS partition (used for LittleFS) needs to be on a coarser boundary than I had it.
    [partitions.csv]
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2025-07-08 Moved kicad files to separate directories and added Passive circuit board
    This will just have a NeoPixel and input and output connectors
    [Passive-B_Cu.gbl, Passive-B_Mask.gbs, Passive-B_Paste.gbp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]
2025-07-08 Added HTTP GET to get the current IP Address.
    Probably won't use it for now but it's there
2025-07-08 Added support for talking to all lights on all posts
    The ESP version will be a single ESP32 with 8 pixel rings on each post, all daisy chained together. This will talk to each group of 8 so each post will still operate indepdently
    Mostly works. There's a bug in multicolor. It flickers on start and one of the colors is blank.
2025-07-10 Changed setAllLights to pass which post to start at and to pass in a color rather than an index
    The problem is that changing a color in the incoming color array will screw up subsequent posts. So now a Color is constructed and passed to setAllLights
2025-08-30 Got WebFileSystem working on esp-idf
    This includes a partitions.csv file which has a single app partition and a LittleFS partition. I'll probably eventually want to make it 2 app partitions for ota
    [partitions.csv]
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2025-09-14 Got the esp-idf build using wifimanager.
    This causes the build to get much bigger so I had to increase the partition size. This shows that the idf build doesn't save that much space compared to the Arduino build. So I'm going to try a different approach
    [partitions.csv]
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2025-10-10 Updated partitions.csv
    Finally got custom partitions working. I had to do this:
    1) exit Arduino IDE
    2) Add the 3 lines from board-local.txt to the boards.txt file at ~/Library/Arduino15/packages/esp32/hardware/esp32/3.3.2
    3) Do a rm -rf ~/Library/Application\ Support/arduino-ide
    4) Restart Arduino IDE
    This partitions.csv gives a bit more room to the OTA partitions so I can have room for Lua
    [partitions.csv]
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2026-04-05 Initial checkin of espidf files for PostLightController
    Not working yet
    [partitions-16mb.csv, partitions-4mb.csv]
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2026-04-09 Added condition_variable to sync tigrUpdate with LED rendering
    Before tigrUpdate could happen in the middle of rendering the LED rings. This would cause flickering. Now I finish the render of the rings and then wait for tigrUpdate to finish. I make sure that we're rendering in a different thread than we update in to avoid deadlocks
    [main.cpp]
2026-04-10 Made Delay in f.lua shorter to account for time taken to execute loop
    [f.lua]
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2026-04-20 Getting rid of old cruft
    [partitions.csv]
2026-04-20 Moved espidf to PostLightController-espidf
    When you give the espidf top-level folder a generic name like this it makes it very confusing which project you're in when you use VSCode
    [partitions-16mb.csv, partitions-4mb.csv]
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2026-05-01 Moved tigrUpdate out of if (needsRender) to avoid the SPOD in the render window
    [main.cpp]
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2026-05-27 Render to offscreen bitmap and then blit it to the display during update.
    This avoids the display tearing
    [main.cpp]
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
